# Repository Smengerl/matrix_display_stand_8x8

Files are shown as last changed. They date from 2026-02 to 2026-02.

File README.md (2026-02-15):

# 8x8 Matrix Display Stand




## Summary
This project provides a clean, professional-looking stand for standard 8x8 WS2812B LED matrices. The modular design features a stable base, integrated ESP32 housing, and a diffuser system for optimal light distribution. Perfect for Home Assistant displays, pixel art, notifications, or custom visualizations.

## Features

- **🖥️ Desktop Stand** - Stable base designed for table placement with professional appearance
- **✨ Clean Aesthetics** - Semi-transparent acrylic cover combined with diffuser system creates a sleek look with retro pixel optics
- **💰 Budget-Friendly** - Complete build for under $10 in components
- **🔌 Smart Integration** - ESP32-based design with WiFi connectivity for Home Assistant and IoT applications
- **🎨 Versatile Display** - Perfect for status displays, notifications, pixel art, weather info, or custom animations
- **🛠️ Easy Assembly** - All parts print without supports; simple assembly with common hardware
- **🔧 Modular Design** - Separate diffuser and grid system for optimal light distribution and customization
- **📐 Standard Compatible** - Works with standard 8x8 WS2812B LED matrices

## Example Applications

* Home Assistant status display
* Solar/battery monitoring
* Weather display
* Notifications
* Pixel art animations
* Retro game displays
* Music visualizer

| Example | Rendering |
| --- | --- |
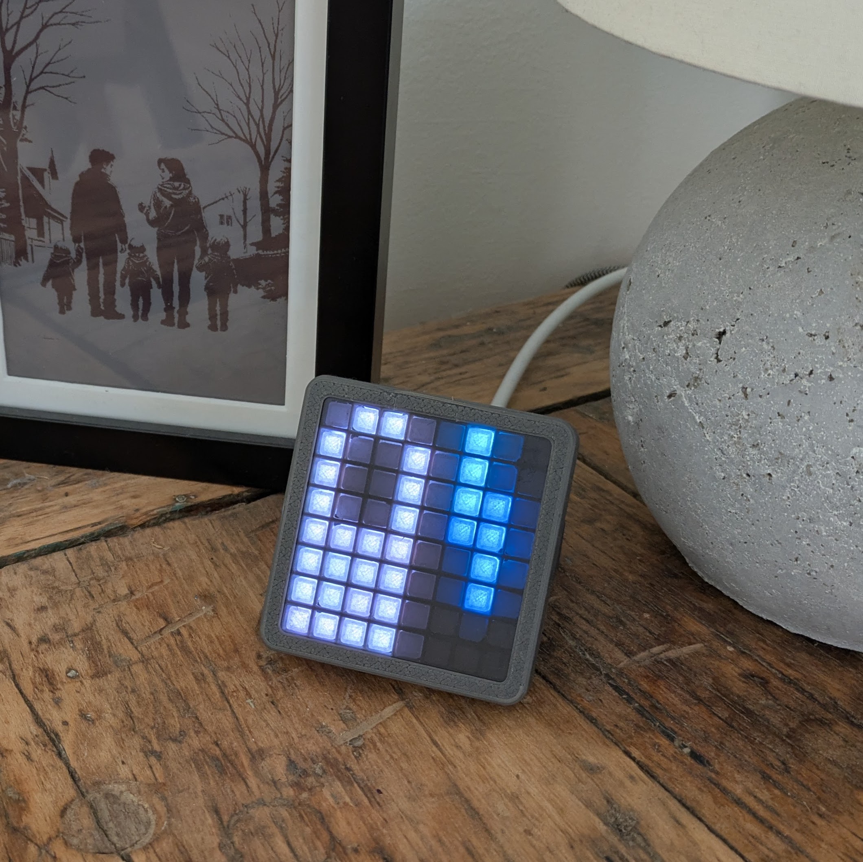
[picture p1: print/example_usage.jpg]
Example usage
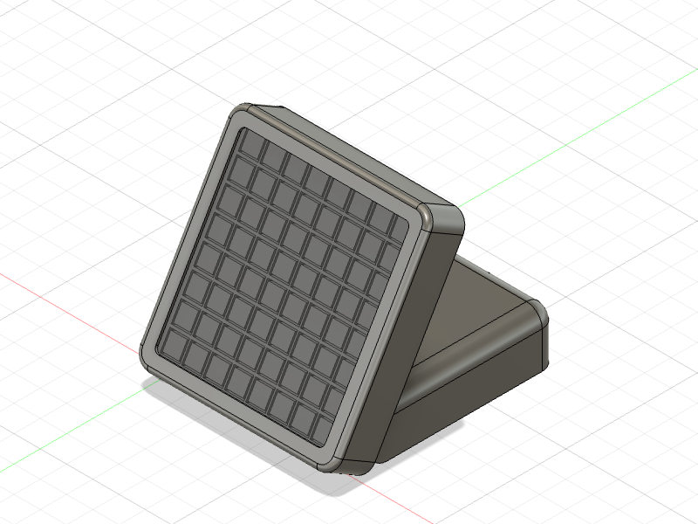
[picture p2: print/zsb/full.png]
Rendering
|  |  | 

| Perspective 1 | Perspective 2 | Perspective 3 |
| --- | --- | --- |
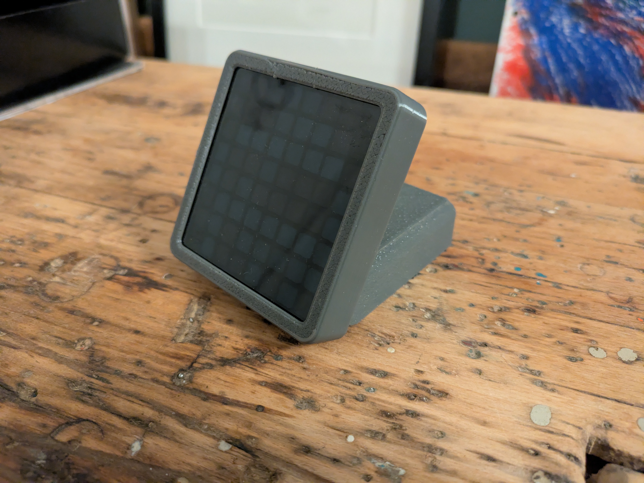
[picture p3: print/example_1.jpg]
Example 1
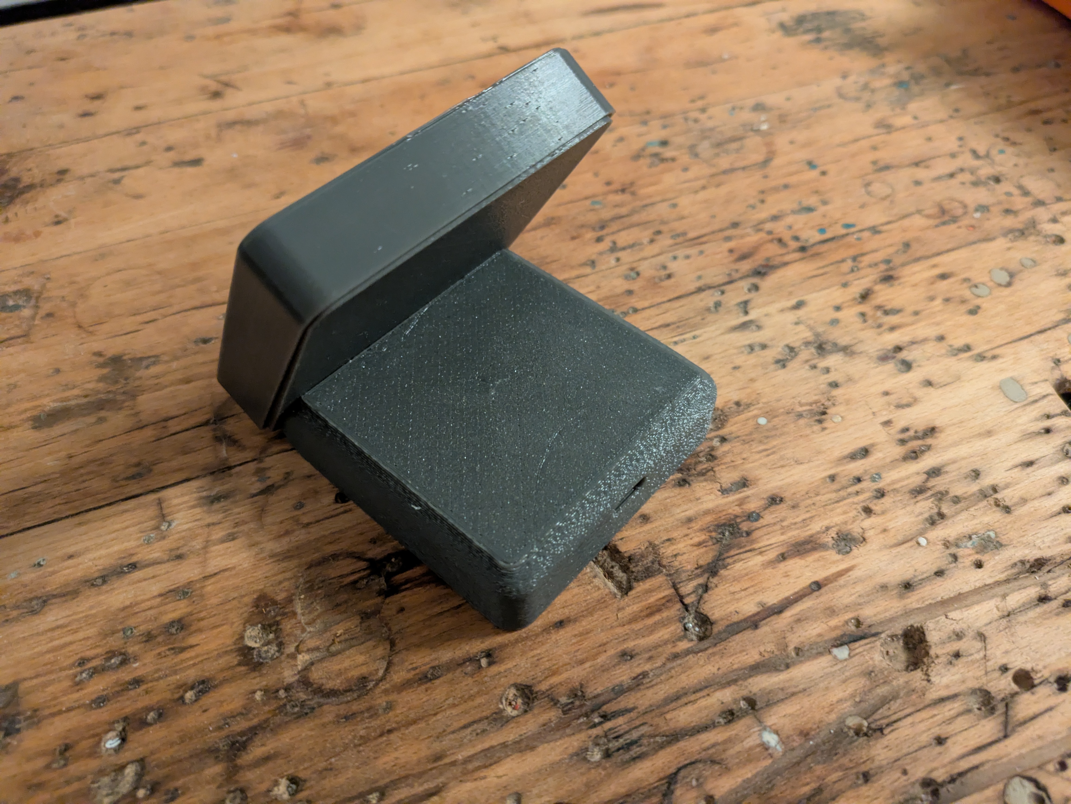
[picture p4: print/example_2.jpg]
Example 2
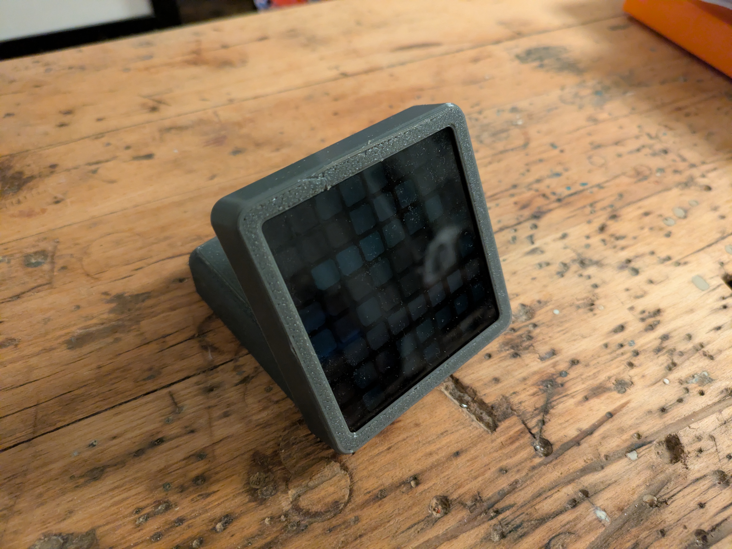
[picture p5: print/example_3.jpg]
Example 3
|  |  |  |

## 3D Printed Parts 

All printable parts and preview images are located in the `print/stl/` and `print/png/` folders.

| Filename | Thumbnail | Notes |
| --- | ---  | ----- |
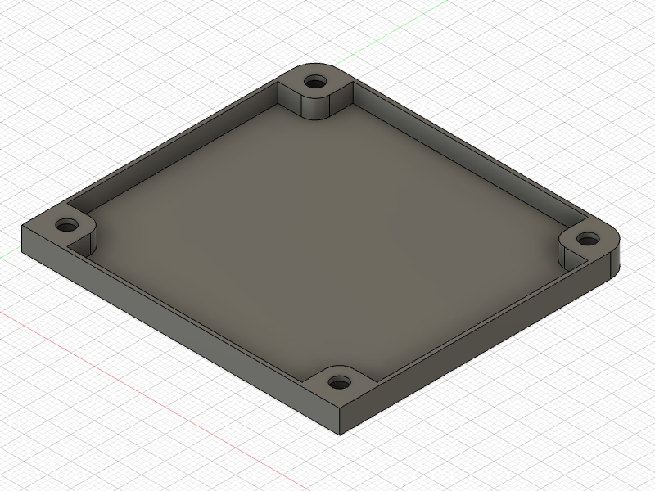
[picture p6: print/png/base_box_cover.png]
| `base_box_cover.stl`|  | Cover for the base |
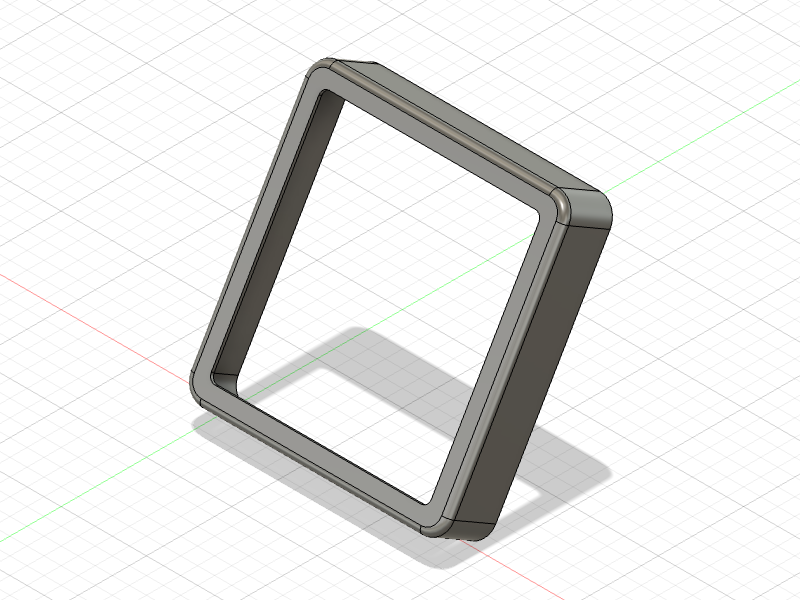
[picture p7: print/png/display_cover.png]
| `display_cover.stl` |  | Display cover |
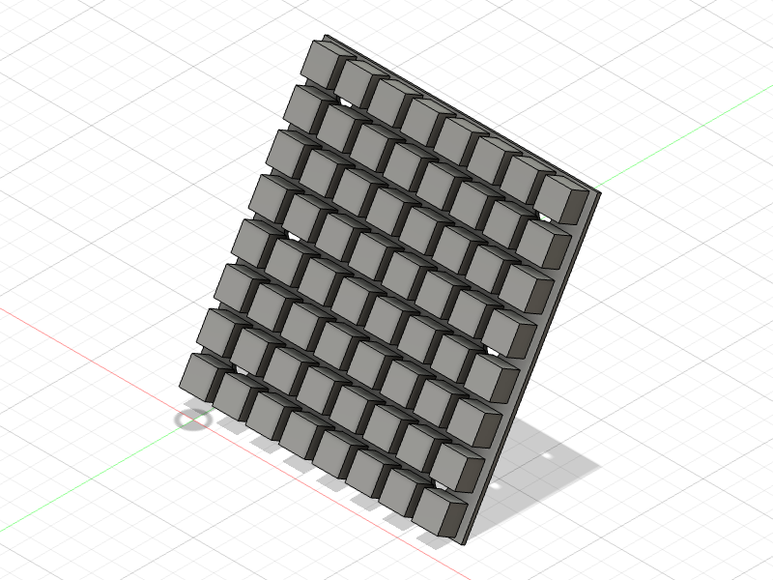
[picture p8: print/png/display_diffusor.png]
| `display_diffusor.stl` |  | Display diffuser - print in translucent PLA |
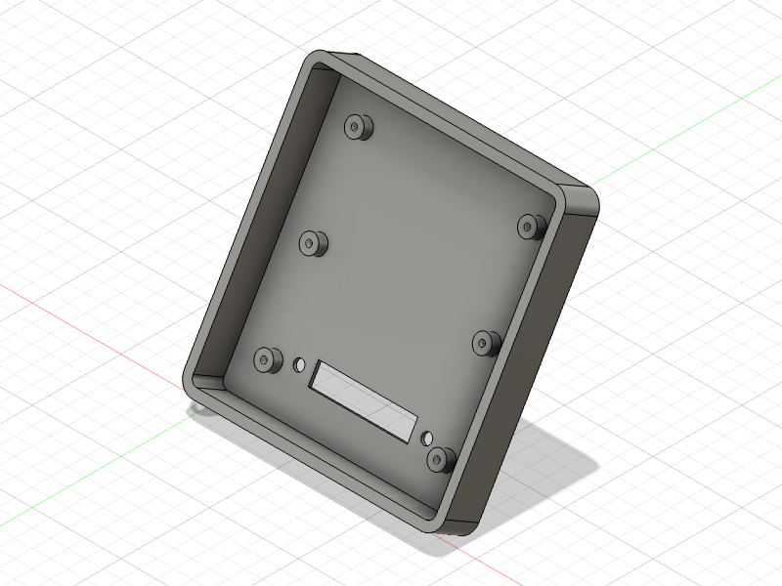
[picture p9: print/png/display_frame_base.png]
| `display_frame_base.stl` |  | Frame base |
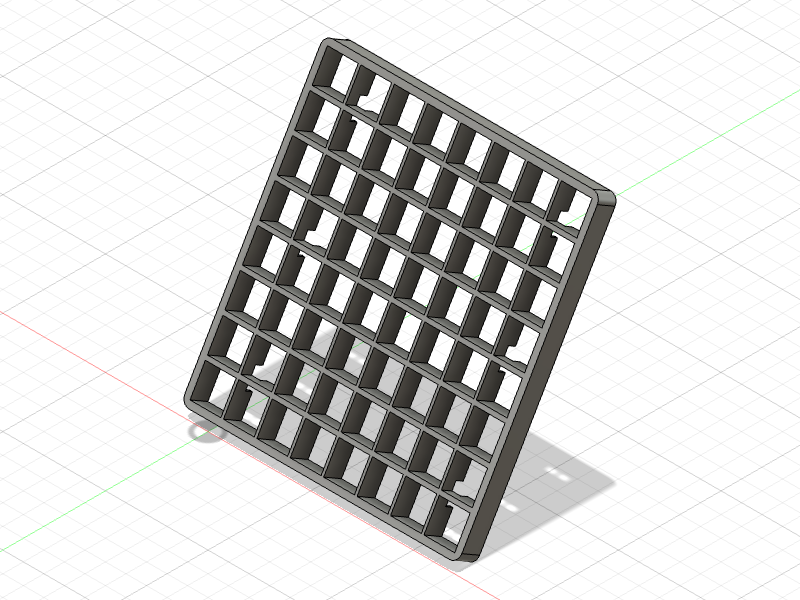
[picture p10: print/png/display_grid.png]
| `display_grid.stl` |  | Grid for diffuser - print in black |

### Print Settings

- **Supports:** None required
- **Material:** PETG or PLA recommended
- **Diffuser:** Print in transparent or semi-transparent material; PLA works best for smooth surfaces and even light distribution
- **Grid:** Recommended to print in black, especially when using blackened acrylic plate

## Bill of Materials

| Unit Price | Quantity | Part Name | Example Link | Notes |
| --- | --- | --- | --- | ----- |
| $5 | 1 | ESP32 Dev Module | [AliExpress](https://de.aliexpress.com/item/1005006474308440.html) | USB-C version recommended |
| $2 | 1 | Semi-transparent Acrylic Board | [AliExpress](https://de.aliexpress.com/item/32857098929.html) | Optional. Best results with semi-transparent black acrylic (2mm thick). Thinner sheets may require adhesive. |
| $2 | 1 | WS2812B 8x8 LED Matrix Module | [AliExpress](https://de.aliexpress.com/item/1005007398953448.html) | Standard 8x8 matrix |

## Hardware Requirements

- 6× M3×10mm cylinder head screws 
- 4× M3×6mm cylinder head screws 
- 6× M2×4mm cylinder head screws 

## Assembly Instructions

1. **Mount ESP32:** Secure the ESP32 to the base using 4× M3×6mm screws
2. **Attach frame base:** Mount the display frame base to the base using 2× M3×10mm screws
3. **Install LED matrix:** 
   - Solder wires to the LED matrix
   - Route the cable through the opening between the display frame base and the base
   - Connect to the ESP32
   - Secure the display to the display frame base using 6× M2×4mm screws
4. **Add diffuser:** Place the diffuser and insert the diffuser grid
5. **Install acrylic panel:** Cut the acrylic plate to size and glue it into the display cover
6. **Final assembly:** Place the display cover on top and optionally secure with adhesive
7. **Close base:** Attach the base cover and secure with 4× M3×10mm screws

See the assembly animation below for visual guidance:

Assembly animation

## Usage Example: Solar and EVCC Control Display

Example implementation for Home Assistant via ESPHome using animated GIFs to showcase the display's capabilities.

This example consolidates solar system and electric vehicle charging (EVCC) status into a single icon. It demonstrates how to implement such use cases in ESPHome and can be easily adapted for other applications.

### Features

* Home battery charge level
* Solar charging battery active (excess solar power stored in battery)
* Solar feeding to grid active (hence consider solar excess charging via EVCC)
* Battery depleted and home is now powered by grid
* Vehicle connected to EVCC charger and charging status

### Example Scenarios

The display combines the battery indicator (left side) with power flow animations (right side) and optional EV overlays:

<table>
<tr>
<th>Scenario</th>
<th>Components</th>
<th>Real Display Photo</th>
</tr>

<tr>
<td><strong>Grid import and EV charging</strong></td>
<td>
• Battery: 10%<br>
• Animation: Grid import (red)<br>
• Overlay: Car charging enabled
</td>
<td>
Grid import with EV charging
</td>
</tr>

<tr>
<td><strong>Solar charging home battery low</strong></td>
<td>
• Battery: 15%<br>
• Animation: Battery Charging (blue)<br>
</td>
<td>
Solar charging home battery low
</td>
</tr>

<tr>
<td><strong>Solar charging home battery full</strong></td>
<td>
• Battery: 95%<br>
• Animation: Battery Charging (blue)<br>
</td>
<td>
Solar charging home battery full
</td>
</tr>

<tr>
<td><strong>Solar power exporting to grid</strong></td>
<td>
• Battery: 100%<br>
• Animation: Grid export (blue)<br>
</td>
<td>
Solar power exporting to grid
</td>
</tr>

</table>

### Battery Status Indicator

The left 4 pixels of the display show the battery state of charge (SOC) with a vertical battery icon:

| SOC Range | Color | Fill Level |
|---|---|---|
| 0-10% | Empty | Empty battery outline |
| 11-25% | 🔴 Red | 1 pixel (bottom) |
| 26-40% | 🟡 Yellow | 2 pixels |
| 41-55% | ⚪ White | 3 pixels |
| 56-70% | ⚪ White | 4 pixels |
| 71-85% | ⚪ White | 5 pixels |
| 86-100% | ⚪ White | 6 pixels (full) |

### Animation overlays

The right 4 pixels of the display show different animations based on the current power flow and EVCC status. The animations are designed to be visually distinct and informative, allowing you to quickly understand the current state of your solar system and EV charging at a glance.

<table>
<tr>
<th>Mode</th>
<th>Display Animation</th>
<th>Description</th>
</tr>

<tr>
<td><strong>Solar Export</strong></td>
<td>
Export animation
</td>
<td>
Exporting solar power to the grid<br>
<em>Triggered when: Power saldo > 100W</em>
</td>
</tr>

<tr>
<td><strong>Grid Import</strong></td>
<td>
Import animation
</td>
<td>
Importing power from the grid<br>
<em>Triggered when: Power saldo < -100W</em>
</td>
</tr>

<tr>
<td><strong>Battery Charging</strong></td>
<td>
Charging animation
</td>
<td>
Charging the home battery<br>
<em>Triggered when: Battery charging power > 0W</em>
</td>
</tr>

<tr>
<td><strong>Pure Grid Power</strong></td>
<td>
Grid image
</td>
<td>
Running on pure grid power (battery depleted)<br>
<em>Triggered when: Battery SOC ≤ 5%</em>
</td>
</tr>

<tr>
<td><strong>Offline</strong></td>
<td>
Offline animation
</td>
<td>
Device disconnected from Home Assistant<br>
<em>Shown when connection is lost</em>
</td>
</tr>

<tr>
<td><strong>EV Charging (Overlay)</strong></td>
<td>
Car overlay
</td>
<td>
Electric vehicle connected and charging enabled<br>
<em>Overlaid when vehicle is connected & charging enabled</em>
</td>
</tr>

<tr>
<td><strong>EV Connected (Overlay)</strong></td>
<td>
Car overlay no charge
</td>
<td>
Electric vehicle connected but charging disabled<br>
<em>Overlaid when vehicle is connected but not charging</em>
</td>
</tr>

</table>

### Prerequisites

- home assistant
- ESP home

### Installation

1. Register the ESP32 with ESPHome (e.g., via ESPHome Web).
2. Rename the device to matrix-display (so that `color-matrix-display.yaml` is the .yaml of your ESP home configuration for the device)
3. Copy the contents of [./ha_scripts](././ha_scripts) to the folder `[homeassistant]/config/esphome`, replacing `color-matrix-display.yaml` and include the images subfolder.
4. Customize the entity names in the yaml according to your configuration
5. Open `color-matrix-display.yaml` in ESPHome and upload the configuration to the device.
6. Once installed, the device will appear in Home Assistant. Set up the device giving it a name 
7. The device will show up in Home Assistant under the ESPHome integration. There you can change the default brigtness or see debug information

## Development

Contributions are welcome! Please see `CONTRIBUTING.md` for details and follow the `CODE_OF_CONDUCT.md` when contributing.

All .stl, .png, and assembly pictures are automatically exported via my Fusion add-in, see [here](https://github.com/smengerl/fusion-exporter)

## License

This project is licensed under the Beerware License — see `LICENSE.txt` for details.

## Author

- Simon Gerlach - [GitHub Profile](https://github.com/Smenger)

---

**Need Help?** If something in this README is missing or unclear, please [open an issue](../../issues) so we can improve the documentation.

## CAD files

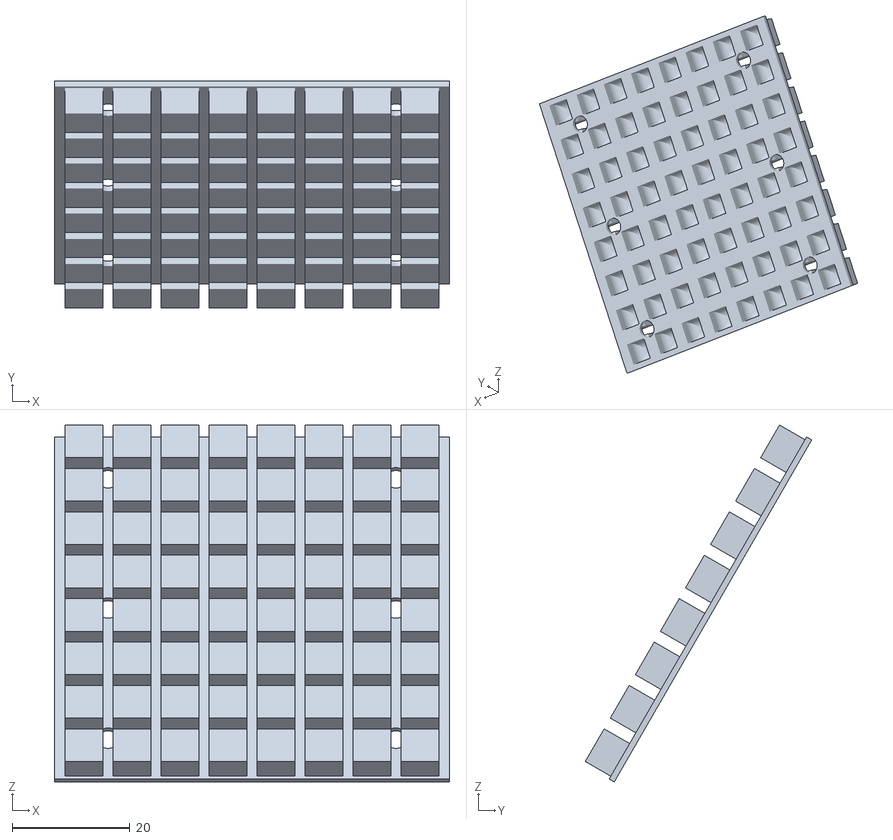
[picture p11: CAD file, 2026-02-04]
print/stl/display_diffusor.stl
67.0 x 38.4 x 60.5

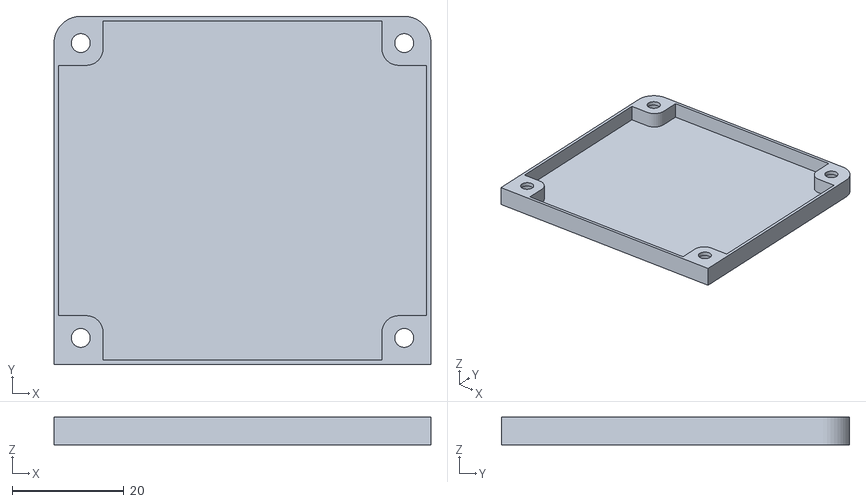
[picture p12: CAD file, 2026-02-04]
print/stl/base_box_cover.stl
67.6 x 62.5 x 5.00

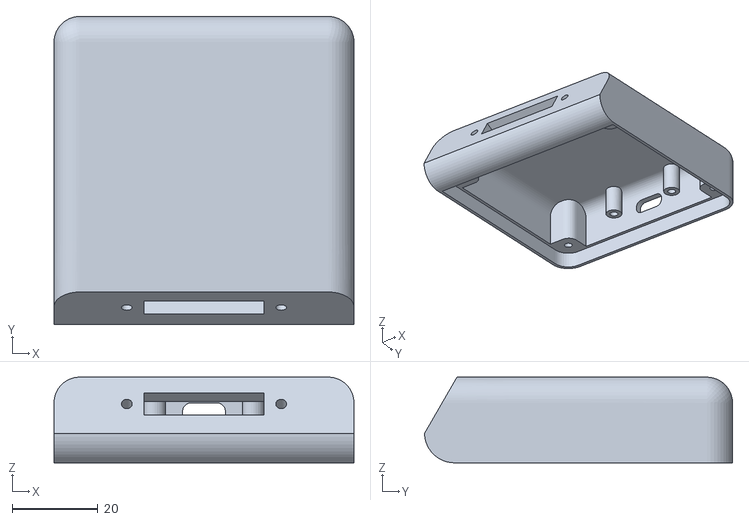
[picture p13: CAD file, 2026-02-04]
print/stl/base_box.stl
70.0 x 71.9 x 20.0

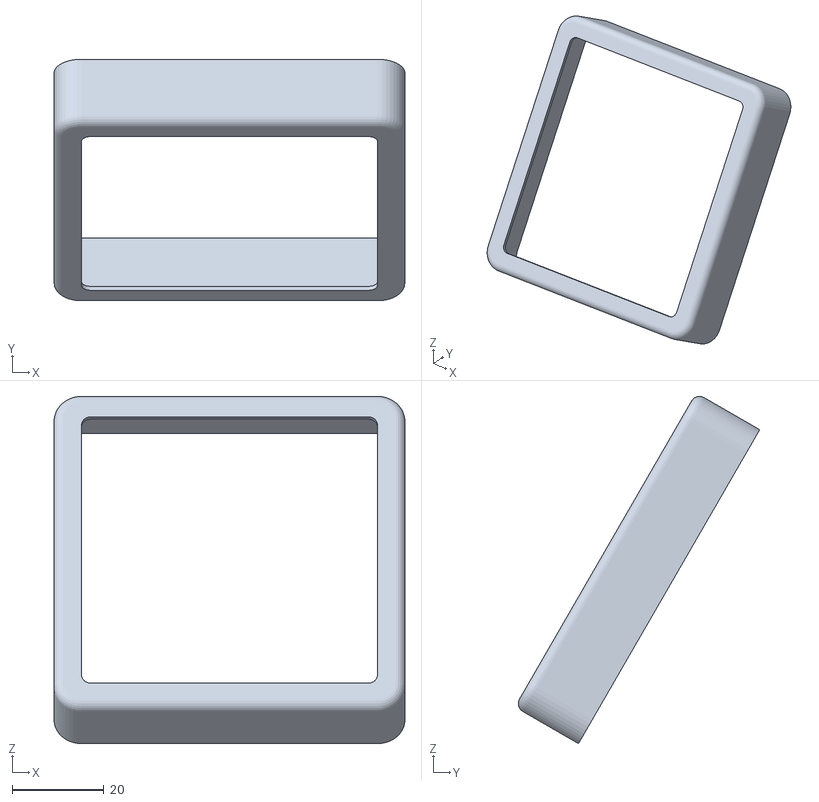
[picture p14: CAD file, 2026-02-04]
print/stl/display_cover.stl
76.5 x 52.6 x 75.7

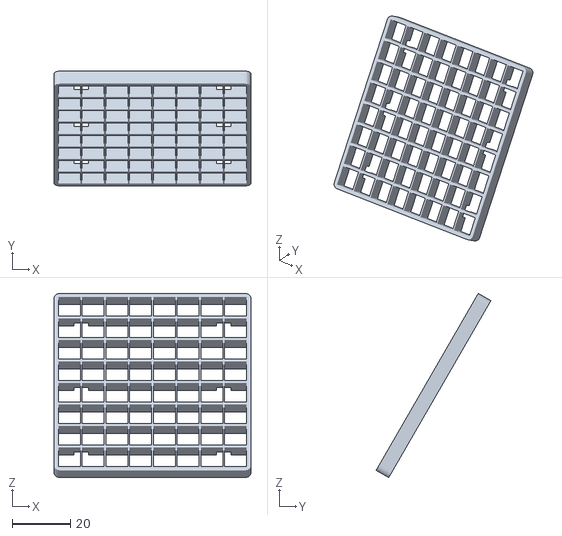
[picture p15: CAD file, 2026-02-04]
print/stl/display_grid.stl
67.5 x 39.3 x 63.1

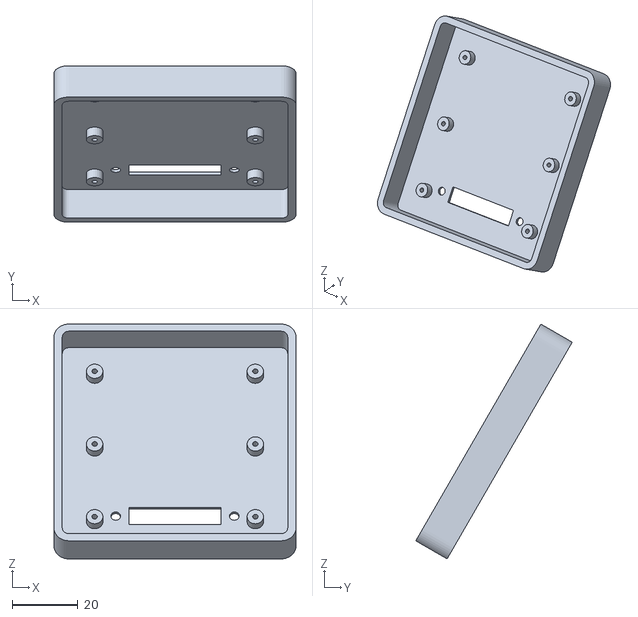
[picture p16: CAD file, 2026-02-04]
print/stl/display_frame_base.stl
73.5 x 47.5 x 71.3

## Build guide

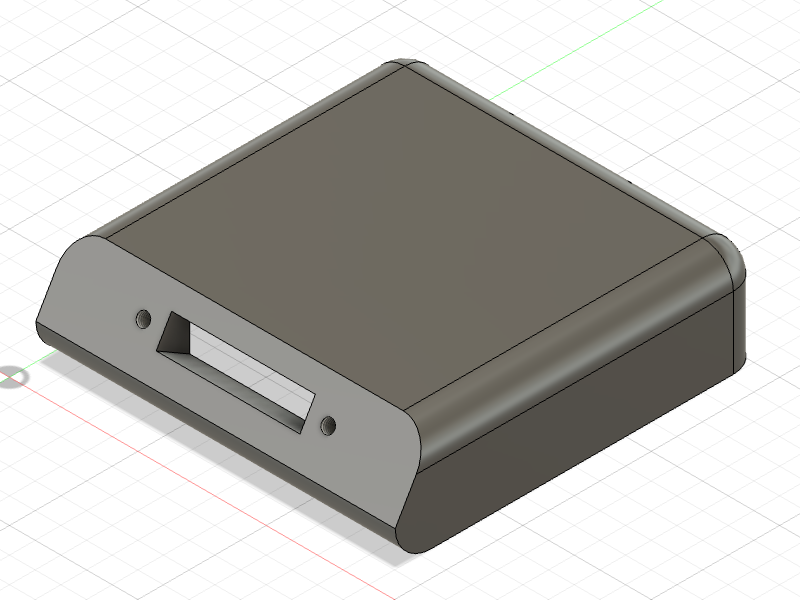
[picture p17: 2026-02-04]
print/png/base_box.png

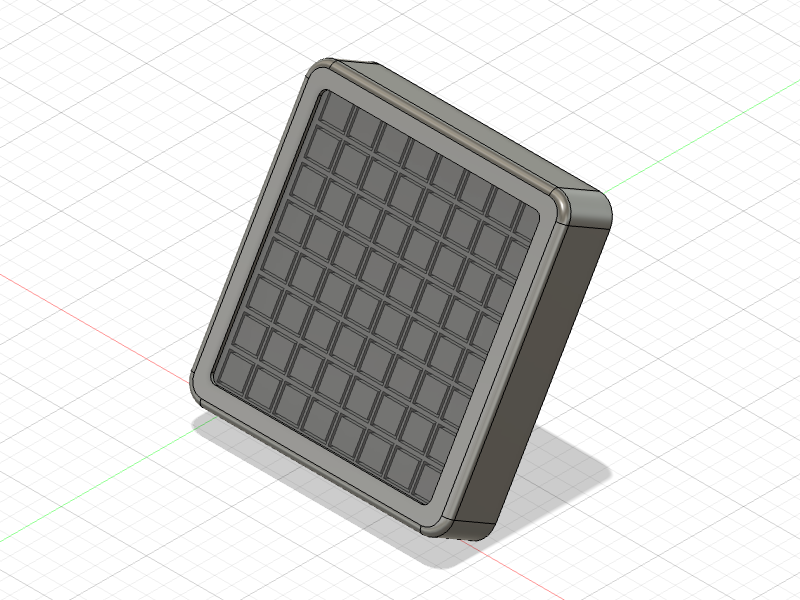
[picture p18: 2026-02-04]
print/zsb/display.png

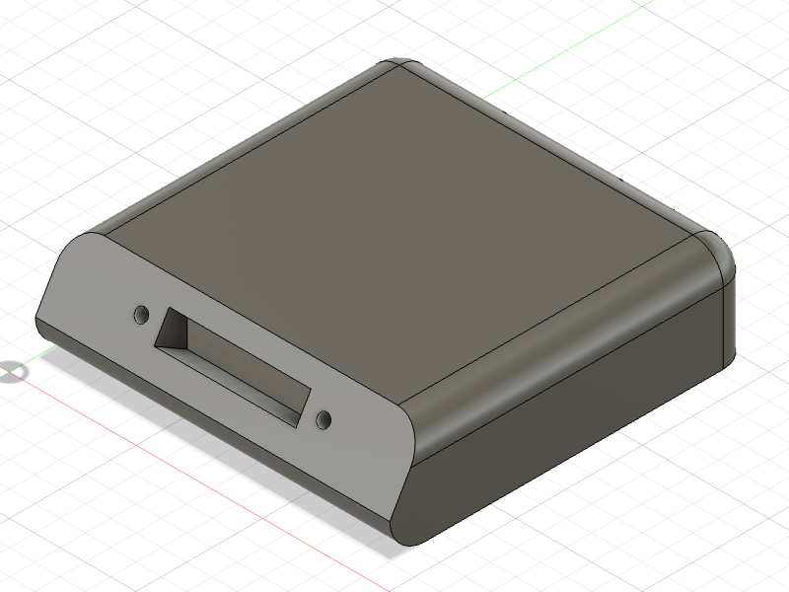
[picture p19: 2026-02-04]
print/zsb/base.png

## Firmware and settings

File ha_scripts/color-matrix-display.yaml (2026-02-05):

###########################################
# 8x8 LED color matrix display
# see: github.com/smengerl/color-matrix-display
###########################################
# EVCC and solar panel status
###########################################
substitutions:
  name: "color-matrix-display"
  friendly_name: Color_Matrix_Display
  comment: Multi purpose color matrix LED display WS2812
  project_name: color_matrix_display.esphome

  TAG: "color-matrix-display.yaml"

  api_key: "7nYxgKZqYw2vT3g9rLhXJvZkQm8sN5cUoWbRzXyTqvE="
  ota_pw: "3f6786b29f445e0ac078c0bfe2e0c81d"
  fallback_hotspot_ssid: "Color Matrix Fallback Hotspot"
  fallback_hotspot_pw: "238asdqvasd3t4d"

  ###########################################
  # Hardware configuration
  ###########################################
  led_pin: GPIO32 # pin for WS2812 display

  ###########################################
  # Display behavior
  ###########################################

  # Number of frames before animation is repeated
  MAX_WAITING_FRAMES: "50"

  ###########################################
  # Sensors - Adapt to your entity IDs in Home Assistant
  # These are used to determine which animation to show on the display based
  # on the current power flow and car charging state
  ###########################################

  ### Solar

  # Batterie SOC
  sensor_battery_soc_entity_id: sensor.battery_state_of_capacity

  # Charging/discharging power of the battery
  sensor_battery_charging_power_entity_id: sensor.battery_charge_discharge_power

  # Power saldo (grid import/export)
  sensor_power_saldo_entity_id: sensor.power_meter_active_power

  ### EVCC

  # charging enabled
  sensor_evcc_charging_active_entity_id: binary_sensor.evcc_garage_enabled

  # Vehicle connected to charger
  sensor_evcc_vehicle_connected_to_charger_entity_id: binary_sensor.evcc_garage_connected

  # Vehicle currently charging
  sensor_evcc_vehicle_currently_charging_entity_id: binary_sensor.evcc_garage_charging # ob gerade in diesem Moment geladen wird

  # sensor.wvwzzzed4se003938_charging_power
  sensor_id7_charging_active_entity_id: switch.wvwzzzed4se003938_charging

packages:
  debug_basics: !include shared_packages/debug_basics.yaml

esphome:
  name: ${name}
  friendly_name: ${friendly_name}
  comment: ${comment}
  name_add_mac_suffix: false
  project:
    name: ${project_name}
    version: "1.0"
  compile_process_limit: 1

esp32:
  board: esp32dev
  framework:
    type: esp-idf

# Enable logging
logger:
#  level: VERBOSE

# Enable Home Assistant API
api:
  encryption:
    key: ${api_key}

ota:
  platform: esphome
  password: ${ota_pw}

wifi:
  id: wifi_id
  ssid: !secret wifi_ssid
  password: !secret wifi_password

  # Enable fallback hotspot (captive portal) in case wifi connection fails
  ap:
    ssid: ${fallback_hotspot_ssid}
    password: ${fallback_hotspot_pw}

# In combination with the `ap` this allows the user to provision wifi credentials to the device via WiFi AP.
captive_portal:

# Displays a notification in case the device need to be updated
dashboard_import:
  package_import_url: github://esphome/example-configs/esphome-web/esp32.yaml@main
  import_full_config: true

###########################################
# Sensors
# These sensors import values from Home Assistant for use in display logic
###########################################
sensor:
  - platform: homeassistant
    id: sensor_battery_soc
    entity_id: $sensor_battery_soc_entity_id

  - platform: homeassistant
    id: sensor_battery_charging_power
    entity_id: $sensor_battery_charging_power_entity_id

  - platform: homeassistant
    id: sensor_power_saldo
    entity_id: $sensor_power_saldo_entity_id
    filters:
      - sliding_window_moving_average:
          window_size: 4 # Sensor updates every 30s - use a 4 value sliding window average to prevent flickering
          send_every: 1
          send_first_at: 1

###########################################
# Binary sensors for car charging state
###########################################
binary_sensor:
  - platform: homeassistant
    id: sensor_evcc_charging_enabled
    entity_id: $sensor_evcc_charging_active_entity_id

  - platform: homeassistant
    id: sensor_evcc_vehicle_connected_to_charger
    entity_id: $sensor_evcc_vehicle_connected_to_charger_entity_id

  - platform: homeassistant
    id: sensor_id7_charging_active
    entity_id: $sensor_id7_charging_active_entity_id

###########################################
# LED matrix light definition
###########################################
light:
  - platform: esp32_rmt_led_strip
    rgb_order: GRB
    pin: ${led_pin}
    num_leds: 64
    chipset: ws2812
    id: led_matrix_light
    name: "Display Brightness"
    restore_mode: RESTORE_DEFAULT_ON
    default_transition_length: 0s
    effects:
      - addressable_lambda:
          name: "Display"
          update_interval: 50ms
          lambda: |-
            // Effect is handled by the display component
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

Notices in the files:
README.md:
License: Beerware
